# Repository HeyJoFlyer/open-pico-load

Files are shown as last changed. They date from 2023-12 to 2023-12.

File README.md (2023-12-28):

# Raspberry Pi Pico Open Source DC Load with OLED Display

This project is an open-source DC load built using a Raspberry Pi Pico microcontroller and an OLED display. It allows users to simulate different loads on power sources, to monitor voltage, current, and power, and display them on an OLED screen.

## Features

- Simulate various loads on DC power sources.
- Measure voltage, current, and other parameters.
- Display real-time data on an OLED screen.
- Open-source design using Raspberry Pi Pico.
- Mine does a maximum 36V and around 7A, max power around 100W
- Handsolderable THT components only
- No exact size or spec requirements for components

## Requirements

- Raspberry Pi Pico microcontroller with circuitpython (you can use the one provided in this repo, i would recommend downloading the newest `.uf2`file from [here](https://circuitpython.org/board/raspberry_pi_pico/)) A Raspberry Pi Pico W will work as well, but would be wasted!
- OLED SSD 1306
- Rotary Encoder
- Big Power Resistor
- 2 Mosfets
- Big Mosfet Heatsink
- 5V Linear Regulator
- Resistors, capacitors, diodes and other electronic components (refer to the schematic or for details) The values are just **approximate**! Your values will **limit the maximum voltage** for the voltage dividers as the Raspberry Pi Pico has a max ADC voltage of 3,3V. The capacitor choice will also affect the maximum input voltage.
- Soldering iron and solder
- PCB (from JLCPCB, PCBWAY or other manufactures, I got mine for 5€)

## Installation

1. `git clone https://github.com/HeyJoFlyer/open-pico-load.git`.

1. Connect the components based on the schematic provided (`schematic.svg`).
schematic

1. Flash the Circuitpython firmware onto the Raspberry Pi Pico.

1. Upload the code and the libraries (which only work for Circuipython 8.x) to the Pico with the file explorer.

## Usage

1. Connect the Board to a DC power source (7-25V, assuming your fan supports that voltage).

1. Connect your load you want to observe using the screw terminal or solder it directly.

1. Adjust the load settings using the rotary encoder.

1. Monitor the voltage, current, and power on the OLED display.

1. Use the load to test different power sources and observe their behavior.

## Contributing

Contributions are welcome! If you'd like to contribute to this project, feel free to fork the repository, make your changes, and submit a pull request.

## License

This project is licensed under the [MIT License](LICENSE).
Circuipython and the libraries included are licensed under the [MIT License](LICENSE).

## Known Bugs (but the load works in real life!):

- The BACK button is not yet implemented in the software
- Current Tracking is not very smooth (I haven't found a good PID alternative in Circuitpython), so the current jumps around a little.
- Circuitpython has a bug with the display driver, so you need to powercycle the board after uploding new `code.py`.
- MOSFETs sometimes blow up (short circuit) if you use to much current or power (I used two active mosfets).

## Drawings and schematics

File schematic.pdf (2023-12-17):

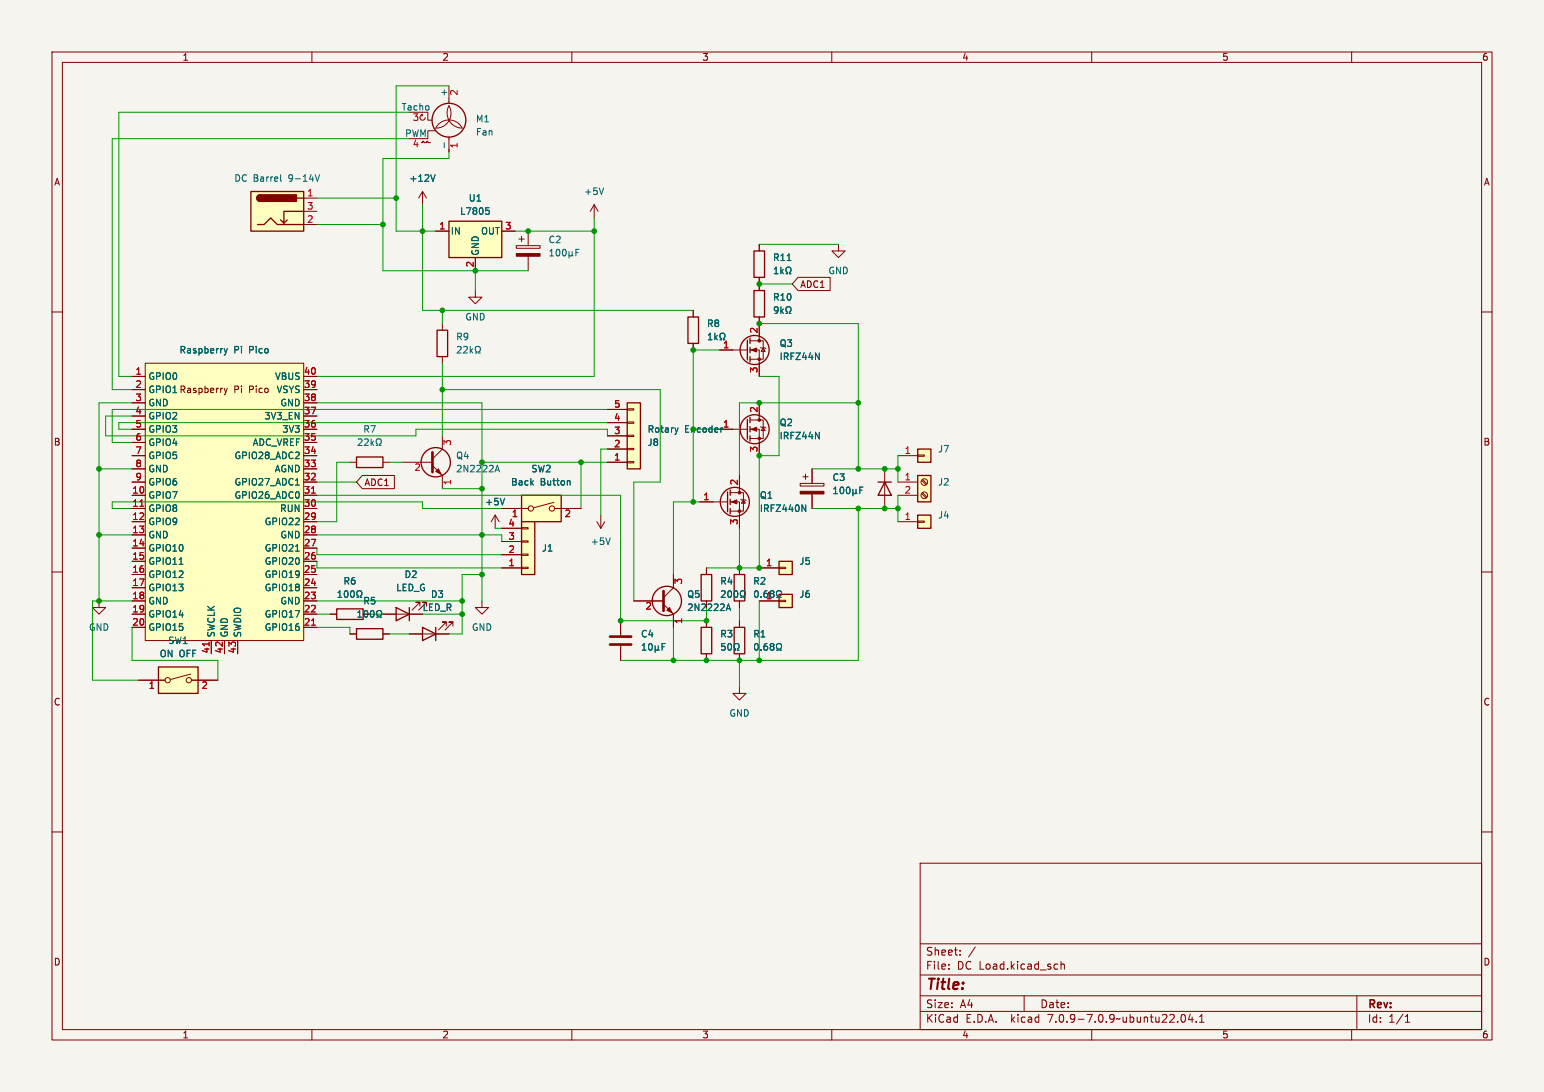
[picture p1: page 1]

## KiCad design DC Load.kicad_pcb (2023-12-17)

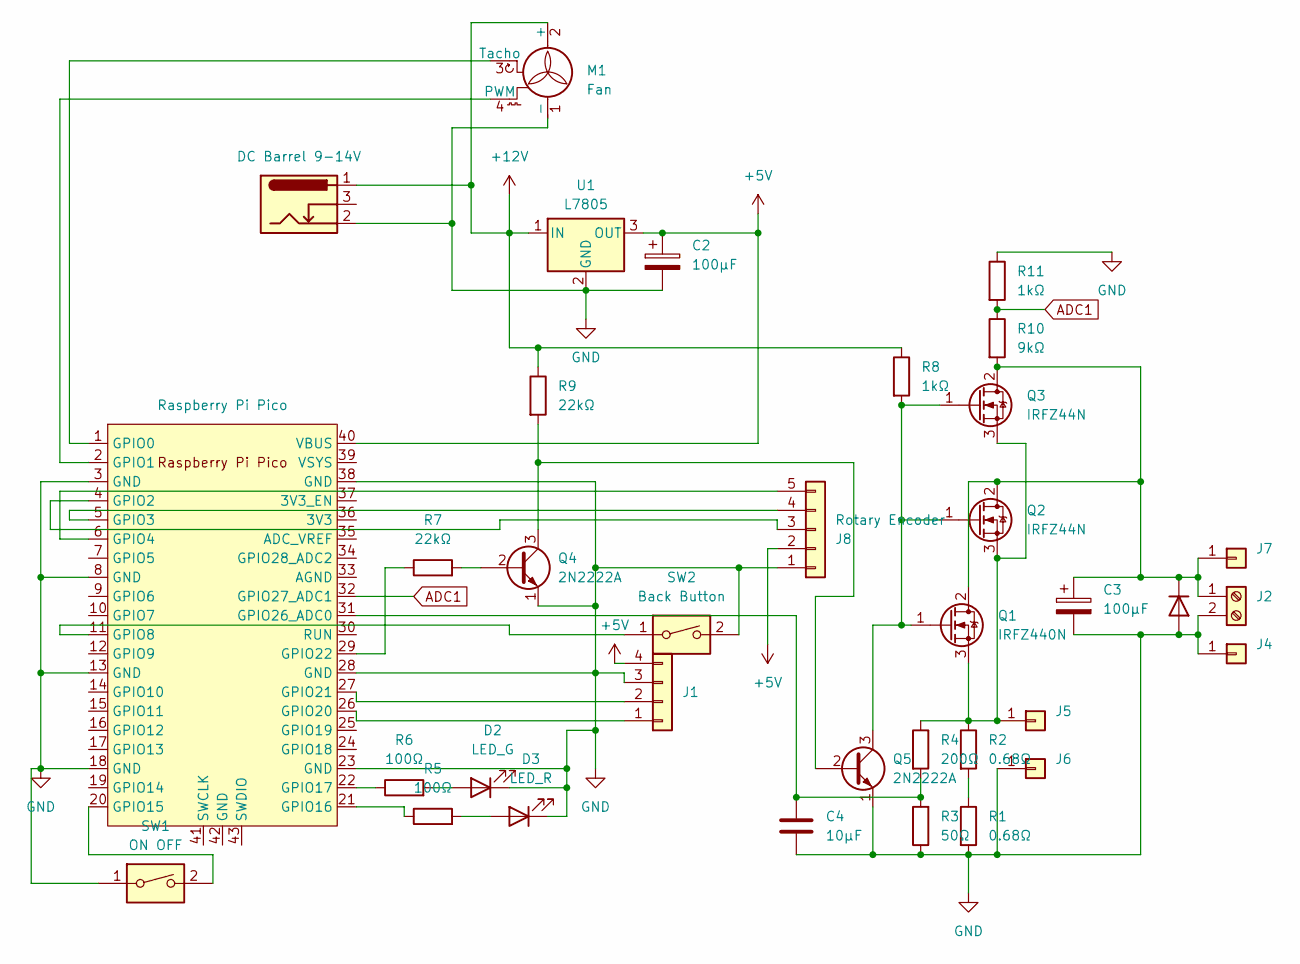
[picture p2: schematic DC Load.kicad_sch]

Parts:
C2: 100µF; CP_Radial_D4.0mm_P2.00mm
C3: 100µF; CP_Radial_D8.0mm_P5.00mm
C4: 10µF; CP_Radial_D4.0mm_P2.00mm
D1: 1N4001; D_DO-41_SOD81_P10.16mm_Horizontal
D2: LED_G; LED_D5.0mm
D3: LED_R; LED_D5.0mm
J1: Conn_01x04; PinHeader_1x04_P2.54mm_Vertical
J2: Screw_Terminal_01x02; TerminalBlock_bornier-2_P5.08mm
J3: DC Barrel 9-14V; BarrelJack_Horizontal
J4, J5, J6, J7: Conn_01x01; Pin_D1.3mm_L11.0mm
J8: Rotary Encoder; PinHeader_1x05_P2.54mm_Vertical
M1: Fan; FanPinHeader_1x04_P2.54mm_Vertical
Q1: IRFZ440N; TO-220-3_Vertical
Q2, Q3: IRFZ44N; TO-220-3_Vertical
Q4, Q5: 2N2222A; TO-92_Inline
R1, R2: 0.68Ω
R3: 50Ω; R_Axial_DIN0309_L9.0mm_D3.2mm_P12.70mm_Horizontal
R4: 200Ω; R_Axial_DIN0309_L9.0mm_D3.2mm_P12.70mm_Horizontal
R5, R6: 100Ω; R_Axial_DIN0309_L9.0mm_D3.2mm_P12.70mm_Horizontal
R7, R9: 22kΩ; R_Axial_DIN0309_L9.0mm_D3.2mm_P12.70mm_Horizontal
R8, R11: 1kΩ; R_Axial_DIN0309_L9.0mm_D3.2mm_P12.70mm_Horizontal
R10: 9kΩ; R_Axial_DIN0309_L9.0mm_D3.2mm_P12.70mm_Horizontal
SW1: ON OFF; SW_PUSH_6mm
SW2: Back Button; SW_PUSH_6mm
U1: L7805; TO-220-3_Vertical
U2: Raspberry Pi Pico; RPi_Pico_SMD_TH

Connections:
+5V: C2.1, J1.4, J8.2, U1.3 (OUT), U2.40 (VBUS)
+12V: J3.1, M1.2 (+), R8.1, R9.1, U1.1 (IN)
ADC1: R10.1, R11.2, U2.32 (GPIO27_ADC1)
GND: C2.2, C3.2, C4.2, D1.2 (A), D2.1 (K), D3.1 (K), J1.3, J2.2, J3.2, J4.1, J6.1, J8.1, M1.1 (-), Q4.1 (E), Q5.1 (E), R1.2, R3.1, R11.1, SW1.1, SW2.2, U1.2 (GND), U2.3 (GND), U2.8 (GND), U2.13 (GND), U2.18 (GND), U2.23 (GND), U2.28 (GND), U2.38 (GND)
unnamed: C3.1, D1.1 (K), J2.1, J7.1, Q1.2 (D), Q2.2 (D), Q3.2 (D), R10.2
unnamed: D2.2 (A), R6.2
unnamed: D3.2 (A), R5.2
unnamed: J1.1, U2.26 (GPIO20)
unnamed: J1.2, U2.27 (GPIO21)
unnamed: J5.1, Q1.3 (S), Q2.3 (S), Q3.3 (S), R2.1, R4.1
unnamed: J8.3, U2.4 (GPIO2)
unnamed: J8.4, U2.5 (GPIO3)
unnamed: J8.5, U2.6 (GPIO4)
unnamed: M1.4 (PWM), U2.2 (GPIO1)
unnamed: M1.3 (Tacho), U2.1 (GPIO0)
unnamed: Q1.1 (G), Q2.1 (G), Q3.1 (G), Q5.3 (C), R8.2
unnamed: Q4.2 (B), R7.2
unnamed: Q4.3 (C), Q5.2 (B), R9.2
unnamed: R1.1, R2.2
unnamed: SW2.1, U2.11 (GPIO8)
unnamed: SW1.2, U2.20 (GPIO15)
unnamed: R5.1, U2.21 (GPIO16)
unnamed: R6.1, U2.22 (GPIO17)
unnamed: R7.1, U2.29 (GPIO22)
unnamed: C4.1, R3.2, R4.2, U2.31 (GPIO26_ADC0)

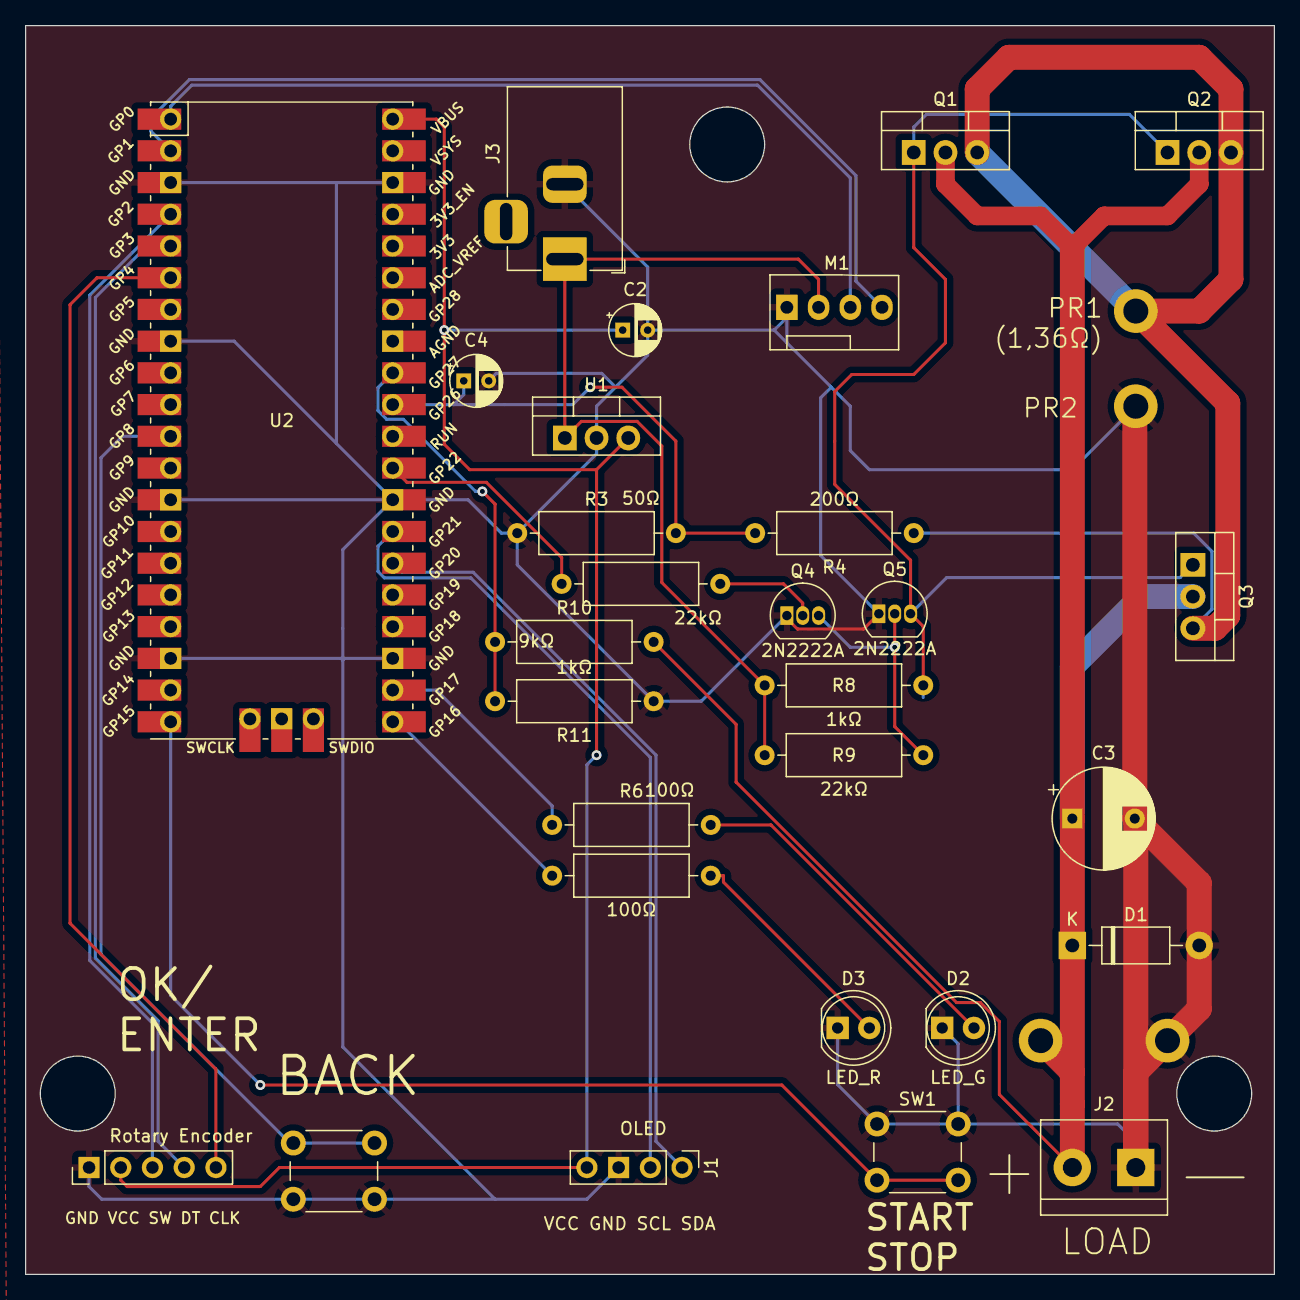
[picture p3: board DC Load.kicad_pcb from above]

Board: 2 copper layers, 100.0 x 100.0 mm, 33 parts (0 on the bottom side), 24 nets.

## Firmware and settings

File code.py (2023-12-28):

# SPDX-FileCopyrightText: 2023 HeyJoFlyer
#
# SPDX-License-Identifier: MIT
import time
import displayio
import adafruit_displayio_ssd1306 #seperate libarary needs to be installed
import terminalio
from adafruit_display_text import label
import board
import busio
import digitalio
from pwmio import PWMOut
from analogio import AnalogIn
from rotaryio import IncrementalEncoder #seperate libarary needs to be installed

#If you haven't changed the board, don't change these values
ENCODER_PIN_1 = board.GP3
ENCODER_PIN_2 = board.GP4
FAN_PIN = board.GP1
TACHO_PIN = board.GP0
OK_BUTTON_PIN = board.GP2 #integrated into rotary encoder
BACK_BUTTON_PIN = board.GP8
ON_BUTTON_PIN = board.GP15
LED_R_PIN = board.GP16
LED_G_PIN = board.GP17
SCL_PIN = board.GP21
SDA_PIN = board.GP20
SHUNT_ADC = board.GP26
MOSFET_PIN = board.GP22
VOLTAGE_ADC = board.GP27

MOSFET_FREQUENCY = 100_000 # you can tune this, 100 kHz worked for me
MAX_CURRENT = 8
VOLT_TO_AMP = 2000 / 548 #you need to change this to your own measured value!
VOLT_TO_VOLT = 400000 / 37264 #you need to change this to your own!
CURRENT_OFFSET = -0.05 #you need to change this to your own or set it to zero!
VOLTAGE_OFFSET = -0.10 #you need to change this to your own or set it to zero!

def pin_setup():
    global fan
    global led_r
    global led_g
    global shunt
    global back_button
    global ok_button
    global on_button
    global encoder
    global mosfet
    global voltage_adc
    fan = PWMOut(FAN_PIN, frequency=25000, duty_cycle=0) # 25kHz for fan
    fan.duty_cycle = 0
    mosfet = PWMOut(MOSFET_PIN, frequency=MOSFET_FREQUENCY, duty_cycle=0)
    fan_tacho = digitalio.DigitalInOut(TACHO_PIN) #optional
    fan_tacho.direction = digitalio.Direction.INPUT #optional
    ok_button = digitalio.DigitalInOut(OK_BUTTON_PIN) #integrated into rotary encoder
    ok_button.direction = digitalio.Direction.INPUT #integrated into rotary encoder
    encoder = IncrementalEncoder(ENCODER_PIN_1, ENCODER_PIN_2)
    back_button = digitalio.DigitalInOut(BACK_BUTTON_PIN)
    back_button.direction = digitalio.Direction.INPUT
    back_button.pull = digitalio.Pull.UP
    on_button = digitalio.DigitalInOut(ON_BUTTON_PIN)
    on_button.direction = digitalio.Direction.INPUT
    on_button.pull = digitalio.Pull.UP
    shunt = AnalogIn(SHUNT_ADC)
    voltage_adc = AnalogIn(VOLTAGE_ADC)
    led_r = digitalio.DigitalInOut(LED_R_PIN)
    led_r.direction = digitalio.Direction.OUTPUT
    led_g = digitalio.DigitalInOut(LED_G_PIN)
    led_g.direction = digitalio.Direction.OUTPUT

def get_power(load_enabled):
    if load_enabled == True:
        current = (shunt.value * VOLT_TO_AMP / 65536 * 3.3) + CURRENT_OFFSET
    else:
        current = 0
    if current < 0:
        current = 0
    voltage = (voltage_adc.value * VOLT_TO_VOLT / 65536 * 3.3) + VOLTAGE_OFFSET
    if voltage < 0:
        voltage = 0
    power = "%.4f" % (current * voltage)
    display_voltage = "%.5f" % voltage
    display_current = "%.5f" % current
    return current, display_current, display_voltage, voltage, power

def integrate(voltage, current, old_time, old_voltage, old_current, total_energy, amp_hours): # This function logs and integrates the total power consumption
    integrate_time  = time.time()
    delta_time = (integrate_time - old_time) / 3600
    avg_current = (current + old_current) / 2
    amp_hours_this_cycle = avg_current * delta_time
    amp_hours += amp_hours_this_cycle
    avg_voltage = (old_voltage + voltage) / 2
    energy_this_cycle = amp_hours_this_cycle * avg_voltage
    total_energy += energy_this_cycle
    total_energy_display = "%.4f" % total_energy
    amp_hours_display = "%.4f" % amp_hours
    return integrate_time, voltage, current, total_energy, amp_hours, total_energy_display, amp_hours_display,

def main():
    # display setup
    i2c = busio.I2C(SCL_PIN, SDA_PIN)
    display_bus = displayio.I2CDisplay(i2c, device_address=0x3c)
    display = adafruit_displayio_ssd1306.SSD1306(display_bus, width=128, height=64)
    splash = displayio.Group()
    display.root_group = splash
    main_label = label.Label(terminalio.FONT, text = "init", color = 0xFFFFFF)
    splash.append(main_label)
    time.sleep(0.3)
    display.show(splash)

    position = 0
    pwm_value = 0
    encoder_enabled = True
    load_enabled = False
    current_setting = 1 # in Amps
    old_button_time = time.time()
    i = 0

    total_energy = float(0)
    amp_hours = float(0)
    old_time = time.time()
    start_time = time.time()
    old_current, _, _, old_voltage, _ = get_power(False)

    while True:
        last_position = position
        position = encoder.position
        current, display_current, display_voltage, voltage, power = get_power(load_enabled)
        old_time, old_voltage, old_current, total_energy, amp_hours, total_energy_display, amp_hours_display = integrate(voltage, current, old_time, old_voltage, old_current, total_energy, amp_hours)
        if on_button.value == False:
            if time.time() - old_button_time > 1:
                old_button_time = time.time()
                load_enabled = not load_enabled
        if load_enabled == True:
            led_g.value = True
            led_r.value = False
        else:
            led_g.value = False
            led_r.value = True
        if current < current_setting:
            pwm_value += 200
        else:
            pwm_value += -200
        if pwm_value < 0 or load_enabled == False:
            pwm_value = 0
        elif pwm_value > 2 ** 16 - 1:
            pwm_value = 2 ** 16 - 1
        mosfet.duty_cycle = pwm_value
        if encoder_enabled == True and last_position != position:
            current_setting += (position - last_position) / 10
            current_setting = round(current_setting, 1)
            if current_setting < 0:
                current_setting = 0

        if i == 100: # only execute every 100th run
            pwm_value_decimal = round(pwm_value / (2 ** 16), 3)
            text = f"\nTarget I: {current_setting}A, {pwm_value_decimal}\n\
I: {display_current}A, {amp_hours_display}Ah\n\
U: {display_voltage}V, T: {round(time.time() - start_time, 1)}s\n\
P: {power}W, {total_energy_display}Wh"
            main_label.text = text
            i = 0
        i += 1
    


pin_setup()
main()
